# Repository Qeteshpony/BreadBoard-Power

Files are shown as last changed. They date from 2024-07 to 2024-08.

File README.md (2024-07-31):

# BreadBoard-Power



3D Render

[Hardware Documentation](https://qeteshpony.github.io/BreadBoard-Power)

A little tool to make prototyping on a solderless breadboard a little easier. Most cheap breadboard power supplies need a lot of space and dont offer modern connections. This one has a USB-C connector as input, is as slim as possible so it can be placed basically anywhere on the breadboard and it has a 1A 3.3V voltage regulator included that allows to put 3.3V on a rail. 

The project includes all production files to get the SMT parts assembled by JLCPCB (not a sponsor) but I used hand-solder-footprints for the smaller parts so it should be quite easy to solder manually, too.

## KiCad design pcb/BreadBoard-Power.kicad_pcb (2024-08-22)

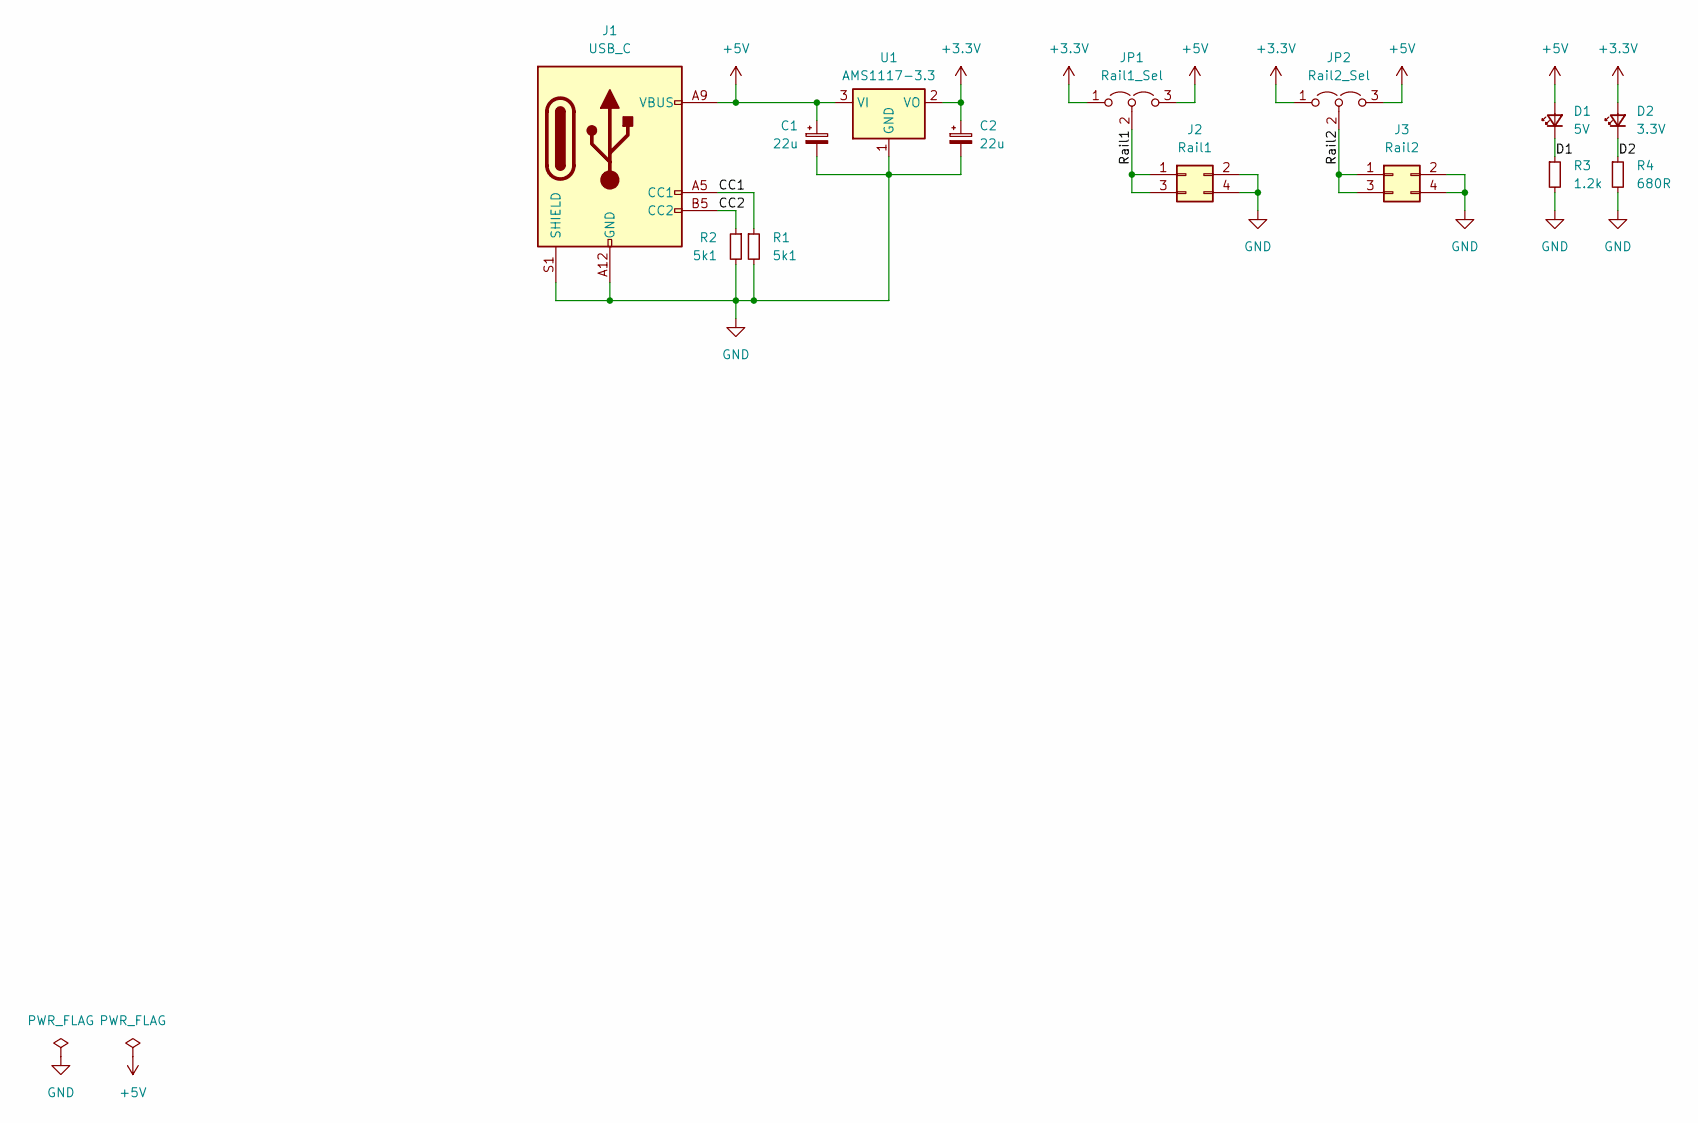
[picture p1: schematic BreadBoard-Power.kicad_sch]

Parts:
C1, C2: 22u; CP_EIA-3216-18_Kemet-A_Pad1.58x1.35mm_HandSolder; LCSC C7171
D1: 5V; LED_0603_1608Metric_Pad1.05x0.95mm_HandSolder; LCSC C2286
D2: 3.3V; LED_0603_1608Metric_Pad1.05x0.95mm_HandSolder; LCSC C2286
J1: USB_C; USB_C_Receptacle_GCT_USB4125-xx-x_6P_TopMnt_Horizontal; LCSC C2763104
J2: Rail1; PinHeader_2x02_P2.54mm_Vertical
J3: Rail2; PinHeader_2x02_P2.54mm_Vertical
JP1: Rail1_Sel; PinHeader_1x03_P2.54mm_Vertical
JP2: Rail2_Sel; PinHeader_1x03_P2.54mm_Vertical
R1, R2: 5k1; R_0603_1608Metric_Pad0.98x0.95mm_HandSolder; LCSC C23186
R3: 1.2k; R_0603_1608Metric_Pad0.98x0.95mm_HandSolder; LCSC C22765
R4: 680R; R_0603_1608Metric_Pad0.98x0.95mm_HandSolder; LCSC C23228
U1: AMS1117-3.3; SOT-223-3_TabPin2; LCSC C6186

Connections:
+3.3V: C2.1, D2.2 (A), JP1.1 (A), JP2.1 (A), U1.2 (VO)
+5V: C1.1, D1.2 (A), J1.A9 (VBUS), J1.B9 (VBUS), JP1.3 (B), JP2.3 (B), U1.3 (VI)
/CC1: J1.A5 (CC1), R1.1
/CC2: J1.B5 (CC2), R2.1
/D1: D1.1 (K), R3.1
/D2: D2.1 (K), R4.1
/Rail1: J2.1, J2.3, JP1.2 (C)
/Rail2: J3.1, J3.3, JP2.2 (C)
GND: C1.2, C2.2, J1.A12 (GND), J1.B12 (GND), J1.S1 (SHIELD), J2.2, J2.4, J3.2, J3.4, R1.2, R2.2, R3.2, R4.2, U1.1 (GND)

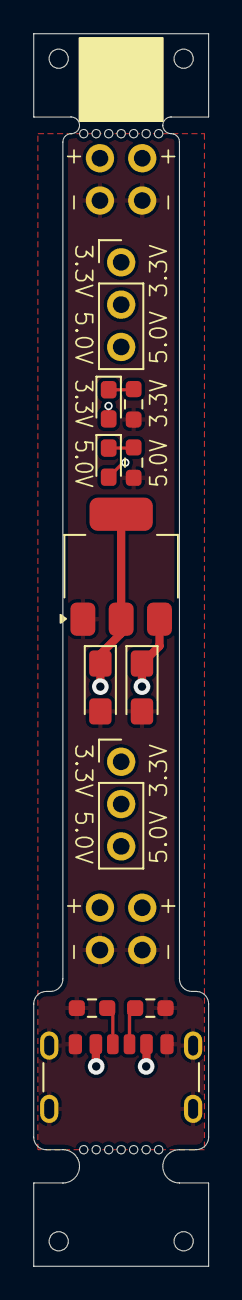
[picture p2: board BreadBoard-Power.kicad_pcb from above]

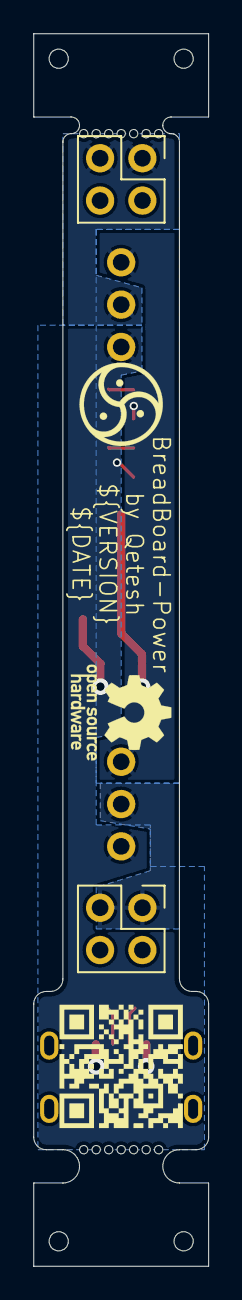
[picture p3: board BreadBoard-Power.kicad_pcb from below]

Board: 2 copper layers, 10.5 x 74.0 mm, 16 parts (2 on the bottom side), 9 nets.

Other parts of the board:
mouse-bite-2mm-slot: VAL**; mouse-bite-2x5mm-slot-onesided-v2
mouse-bite-2mm-slot#2: VAL**; mouse-bite-2x5mm-slot-onesided-no-edge

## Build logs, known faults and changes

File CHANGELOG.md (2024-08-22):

# Changelog

## [1.1.0](https://github.com/Qeteshpony/BreadBoard-Power/compare/v1.0.1...v1.1.0) (2024-08-22)

### Features

* add production rails ([e48a5a5](https://github.com/Qeteshpony/BreadBoard-Power/commit/e48a5a5905392769a3303ae92d69a64904d9a8bd))

## [1.0.1](https://github.com/Qeteshpony/BreadBoard-Power/compare/v1.0.0...v1.0.1) (2024-08-21)

### Bug Fixes

* add missing logos ([d174363](https://github.com/Qeteshpony/BreadBoard-Power/commit/d174363b4756574aefcbf40b7c2486e646d240d0))

## 1.0.0 (2024-08-21)

### Features

* initial commit ([6e5b7bf](https://github.com/Qeteshpony/BreadBoard-Power/commit/6e5b7bfbdbdf37457aae23da17f19694a99c8542))

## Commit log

2024-07-31 feat: initial commit
    [BreadBoard-Power.kicad_pcb, BreadBoard-Power.kicad_sch]
2024-08-21 docs: schematic cleanup
    [BreadBoard-Power.kicad_pcb, BreadBoard-Power.kicad_sch]
2024-08-21 fix: add missing logos
    [BreadBoard-Power.kicad_pcb]
2024-08-22 feat: add production rails
    [BreadBoard-Power.kicad_pcb]
